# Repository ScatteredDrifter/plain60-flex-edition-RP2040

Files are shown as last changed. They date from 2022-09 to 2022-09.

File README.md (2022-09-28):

# Plain60 Flex Edition rev2.2

This universal 60% PCB is designed to support as little layouts as possible without limiting usability for most users. The reason I did this is because other PCBs made for this form factor usually have so many supported layouts that it could almost qualify as swiss cheese.

It also features a fuse and an ESD protection chip to protect the MCU and other parts of the PCB.

## Features ::
- built with rp2040 and 128 M-Bit flash  
- Fits in the TGR Unikorn
- supports QMK and VIAL 
- Compatible with most universal 60% cases and HHKB/WKL Tofu by KBDfans
- USB type-C
- Optional JST header for connection with daughterboard
- Footprint for optional speaker (AST1109MLTRQ)
- ESD protection and fuse
- underglow with 8 Leds 
- *not as minimal* layout support
- - bottom row :: 6u, 7u, 6.25u, split-space 2.25u,1u,2.75u
- - split-backspace 
- - split L-shift and R-shift

## Supported layouts
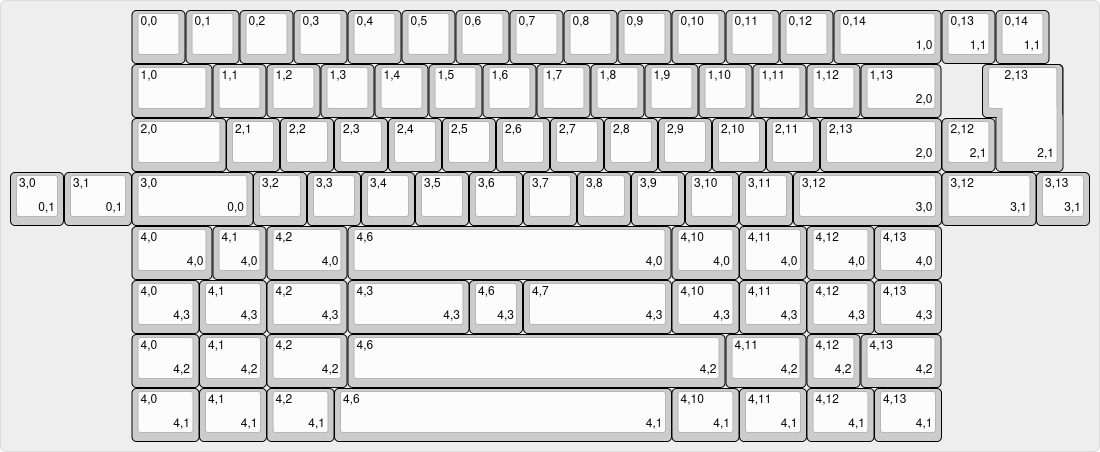
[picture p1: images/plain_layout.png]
Supported layouts of the plain-60


## Building ::
If you feel like building a few of these PCBs yourself, go to the 'Releases' tab and download the latest gerber files. Order those at your favourite PCB manufacturer, get the components needed (see below) and solder them on! A hot air station is not required but a soldering iron is. Flux is recommended.

## Images :: 
![images of prototypes]()
![images of prototypes]()

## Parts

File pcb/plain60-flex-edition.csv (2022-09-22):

Comment | Designator | Footprint | LCSC
BOOT | BOOT1 | Keebio-Parts:SW_SPST_TL3342 | C2886894
10u | C1,C4,C17 | Capacitor_SMD:C_0805_2012Metric | C91245
22pf | C2,C3 | Capacitor_SMD:C_0805_2012Metric | C1804
100n | C5,C6,C7,C9,C11,C12,C13,C14 | Capacitor_SMD:C_0805_2012Metric | C49678
1u | C8,C10 | Capacitor_SMD:C_0805_2012Metric | C28323
BAV70 | D1,D2,D3,D4,D5,D6,D7,D8,D9,D10,D11,D12,D13,D14,D15,D16,D17,D18,D19,D20,D21,D22,D23,D24,D25,D26,D27,D28,D29,D30,D31,D32,D33,D34 | Package_TO_SOT_SMD:SOT-23 | C68978
polyfuse | F0 | Fuse:Fuse_1206_3216Metric | C69688
USB_C_Receptacle_USB2.0 | J0 | Connector_USB:USB_C_Receptacle_HRO_TYPE-C-31-M-12 | C165948
BREAKOUT | J1 | Connector_PinSocket_2.54mm:PinSocket_1x05_P2.54mm_Vertical
ai03_ud | J2 | Connector_JST:JST_SH_SM04B-SRSS-TB_1x04-1MP_P1.00mm_Horizontal
Conn_01x01_Male | J4,J5 | Connector_PinSocket_1.27mm:PinSocket_1x01_P1.27mm_Vertical
KEYSW | K1,K2,K3,K4,K5,K6,K7,K8,K9,K10,K11,K12,K13,K14,K17,K18,K19,K20,K21,K22,K23,K24,K25,K26,K27,K28,K32,K33,K34,K35,K36,K37,K38,K39,K40,K41,K42,K43,K47,K48,K49,K50,K51,K52,K53,K54,K55,K56,K57,K59,K15-1,K62-1,K73-1 | Keeb_switches:CHERRY_PLATE_100H
KEYSW | K15 | Keeb_switches:CHERRY_PCB_200H
KEYSW | K16,K29,K61-1,K63-1,K72-1,K74-1 | Keeb_switches:CHERRY_PLATE_150H
KEYSW | K31,K58-1 | Keeb_switches:CHERRY_PLATE_175H
KEYSW | K61,K62,K63,K71,K72,K73,K74,K31-1,K46-1 | Keeb_switches:CHERRY_PLATE_125H
KEYSW | K44 | Keeb_switches:CHERRY_PCB_225H_F
KEYSW | K44-1 | Keeb_switches:CHERRY_PCB_200H_V
KEYSW | K46 | Keeb_switches:CHERRY_PCB_225H
KEYSW | K58 | Keeb_switches:CHERRY_PCB_275H
KEYSW | K67 | Keeb_switches:CHERRY_PCB_625H_F
KEYSW | K67-1 | Keeb_switches:CHERRY_PCB_700H_F
KEYSW | K67-2,K67-3,K67-4 | keyswitches:SW_MX
WS2812B | LED2,LED3,LED5,LED6,LED7,LED8,LED9,LED10 | kbd:LED_WS2812B-PLCC4
Speaker | LS0 | Keebio-Parts:AST1109MLTRQ
1k | R1,R5 | Resistor_SMD:R_0805_2012Metric | C115316
27 | R3,R4 | Resistor_SMD:R_0805_2012Metric | C104170
5.1k | R6,R7 | Resistor_SMD:R_0805_2012Metric | C27834
10k | R8 | Resistor_SMD:R_0805_2012Metric | C115309
RESET | RESET1 | Keebio-Parts:SW_SPST_TL3342 | C2886894
Screw | S1,S2,S3,S6 | footprints:5.5_5x2.5mm
Screw | S4,S5 | footprints:10x5_7x2.5mm
Tofu screw | S7,S8,S9 | footprints:5.5_5x2.5mm
NCP1117-3.3_SOT223 | U1 | Package_TO_SOT_SMD:SOT-223-3_TabPin2 | C26537
W25Q128JVS | U2 | Package_SO:SOIC-8_5.23x5.23mm_P1.27mm | C97521
RP2040 | U3 | RP2040:RP2040-QFN-56 | C2040
SRV05-4 | U44 | Package_TO_SOT_SMD:SOT-23-6 | C85364
12MHZ Crystal | Y0 | Crystal:Crystal_SMD_3225-4Pin_3.2x2.5mm | C9002

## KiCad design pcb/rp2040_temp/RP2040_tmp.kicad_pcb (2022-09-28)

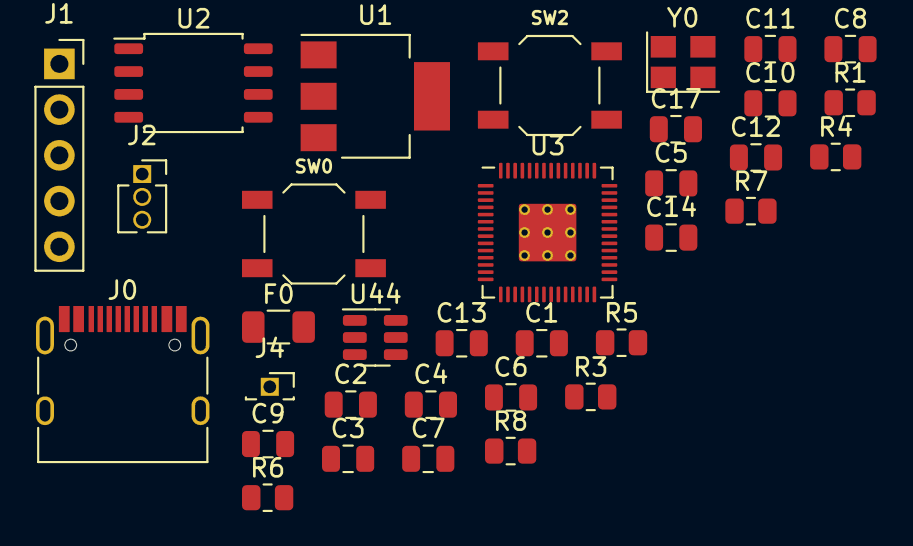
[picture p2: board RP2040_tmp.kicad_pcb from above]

Board: 2 copper layers, 34 parts (0 on the bottom side), 25 nets, no tracks yet.

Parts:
C1, C4, C17: 10u; C_0805_2012Metric
C2, C3: 22pf; C_0805_2012Metric
C5, C6, C7, C9, C11, C12, C13, C14: 100n; C_0805_2012Metric
C8, C10: 1u; C_0805_2012Metric
F0: polyfuse; Fuse_1206_3216Metric
J0: USB_C_Receptacle_USB2.0; USB_C_Receptacle_HRO_TYPE-C-31-M-12
J1: BREAKOUT; PinSocket_1x05_P2.54mm_Vertical
J2: Conn_01x03_Male; PinSocket_1x03_P1.27mm_Vertical
J4: Conn_01x01_Male; PinSocket_1x01_P1.27mm_Vertical
R1, R5: 1k; R_0805_2012Metric
R3, R4: 27; R_0805_2012Metric
R6, R7: 5.1k; R_0805_2012Metric
R8: 10k; R_0805_2012Metric
SW0, SW2: RESET; SW_SPST_TL3342
U1: NCP1117-3.3_SOT223; SOT-223-3_TabPin2
U2: W25Q128JVS; SOIC-8_5.23x5.23mm_P1.27mm
U3: RP2040; RP2040-QFN-56
U44: SRV05-4; SOT-23-6
Y0: 12MHZ Crystal; Crystal_SMD_3225-4Pin_3.2x2.5mm

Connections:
+1V1: C6.1, C7.1, C8.1, J4.1, U3.23 (DVDD), U3.45 (VREG_VOUT), U3.50 (DVDD)
+3V3: C4.1, C5.1, C9.1, C10.1, C11.1, C12.1, C13.1, C14.1, C17.1, J1.2, R8.2, U1.2 (VO), U2.8 (VCC), U3.1 (IOVDD), U3.10 (IOVDD), U3.22 (IOVDD), U3.33 (IOVDD), U3.42 (IOVDD), U3.43 (ADC_AVDD), U3.44 (VREG_IN), U3.48 (USB_VDD), U3.49 (IOVDD)
+5V: C1.1, F0.2, J2.1, U1.3 (VI), U44.5 (VP)
/QSPI_SCLK: U2.6 (CLK), U3.52 (QSPI_SCLK)
/QSPI_SD0: U2.5 (DI(IO0)), U3.53 (QSPI_SD0)
/QSPI_SD1: U2.2 (DO(IO1)), U3.55 (QSPI_SD1)
/QSPI_SD2: U2.3 (IO2), U3.54 (QSPI_SD2)
/QSPI_SD3: U2.7 (IO3), U3.51 (QSPI_SD3)
/QSPI_SS: R1.1, U2.1 (~CS), U3.56 (QSPI_SS)
/RUN: J1.1, R8.1, SW2.2, U3.26 (RUN)
/SWCLK: J1.5, U3.24 (SWCLK)
/SWD: J1.4, U3.25 (SWD)
/USB_D+: J0.A6 (D+), J0.B6 (D+), R3.1, U44.3 (IO2)
/USB_D-: J0.A7 (D-), J0.B7 (D-), R4.1, U44.6 (IO4)
/XIN: C2.1, U3.20 (XIN), Y0.3
/XOUT: R5.1, U3.21 (XOUT)
/~USB_BOOT: R1.2, SW0.2
GND: C1.2, C2.2, C3.2, C4.2, C5.2, C6.2, C7.2, C8.2, C9.2, C10.2, C11.2, C12.2, C13.2, C14.2, C17.2, J0.A1 (GND), J0.A12 (GND), J0.B1 (GND), J0.B12 (GND), J0.S1 (SHIELD), J1.3, J2.2, R6.2, R7.2, SW0.1, SW2.1, U1.1 (GND), U2.4 (GND), U3.19 (TESTEN), U3.57 (GND), U44.2 (VN), Y0.2, Y0.4
LED_GLOW: J2.3, U3.8 (GPIO6)
unnamed: C3.1, R5.2, Y0.1
unnamed: J0.A5 (CC1), R7.1
unnamed: J0.B5 (CC2), R6.1
unnamed: R3.2, U3.47 (USB_DP)
unnamed: R4.2, U3.46 (USB_DM)
VBUS: F0.1, J0.A4 (VBUS), J0.A9 (VBUS), J0.B4 (VBUS), J0.B9 (VBUS)

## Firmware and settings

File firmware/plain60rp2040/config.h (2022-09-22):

// Copyright 22 ScatteredDrifter / fabiansta

#pragma once

#include "config_common.h"

/* --- USB Device properties --- */
#define VENDOR_ID 0xFAB0
#define PRODUCT_ID 0xFAB1
#define DEVICE_VER 0x0001
#define MANUFACTURER ScatteredDrifter
#define PRODUCT plain60rp2040

/* --- Matrix definition --- */
#define MATRIX_ROWS 5 
#define MATRIX_COLS 15

/* --- Matrix assignment --- */ 
#define MATRIX_COL_PINS \
    { GP24, GP25, GP4, GP5, GP6, GP7, GP8, GP9, GP10, GP11, GP12, GP15, GP14, GP13, GP23 }
#define MATRIX_ROW_PINS \
    { GP1, GP3, GP0, GP2, GP21 }


/* --- additional settings --- */
#define DEBUG_MATRIX_SCAN_RATE
#define LAYER_STATE_16BIT
// reducing chattering, set to 0 if not necessary 
#define DEBOUNCE 5 
#define DIODE_DIRECTION COL2ROW

/* --- rgb settings --- */
//#define RGB_MATRIX_FRAMEBUFFER_EFFECTS
//#define RGB_MATRIX_KEYPRESSES
#define RGB_DI_PIN GP22
#define RGBLED_NUM 8
#define NOP_FUDGE 0.5
#define DRIVER_LED_TOTAL RGBLED_NUM 

//#define QMK_WAITING_TEST_BUSY_PIN GP8
//#define QMK_WAITING_TEST_YIELD_PIN GP9

/* --- RP2040 specific settings */
#define RP2040_BOOTLOADER_DOUBLE_TAP_RESET
//#define RP2040_BOOTLOADER_DOUBLE_TAP_RESET_LED GP25
#define RP2040_BOOTLOADR_DOUBLE_TAP_RESET_TIMEOUT 500U

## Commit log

2022-09-22 updated pcb, firmware, parts
    [plain2040-bom.csv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]
2022-09-28 updated pcb
